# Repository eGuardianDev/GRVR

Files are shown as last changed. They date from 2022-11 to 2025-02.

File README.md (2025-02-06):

<div align="center" display="inline">
  <h1>Gyroscope Tracking (in) Virtual Reality</h1>

<h3>This project allows you to track points in 3d invieroment using gyroscopes.</h3>

<h4>This gives you the ability you to track your body. Uses can be found in VR Gaming, AR interfaces, sport and physical tracking, Location estimation
</h4>
</div>

<br/>
<h2>Current State:</h2>

- [X] Point localization algorithm 
- [X] API implementation
- [X] Custom json file on configuration
- [X] ESP-NOW Communication
- [ ] Controllers
- [ ] Movement algorithm
- [ ] Headset display

<h2> Tech Stack </h2>

||Hardware|Software|Additional|
|:---:|:---:|:---:|:---:|
||ESP8266|AvaloniaUI|SteamVR|
||MPU6050| |Panda3d|
||C++| C#| C++ & Python|

## Documentation

[Documentation](https://github.com/eGuardianDev/GRVR/wiki)

## Limitations
#### 1. Many sensors are needed to track every main point of the body.
#### 2. Every point should have a "parent" point. (Except point zero)

## Pictures
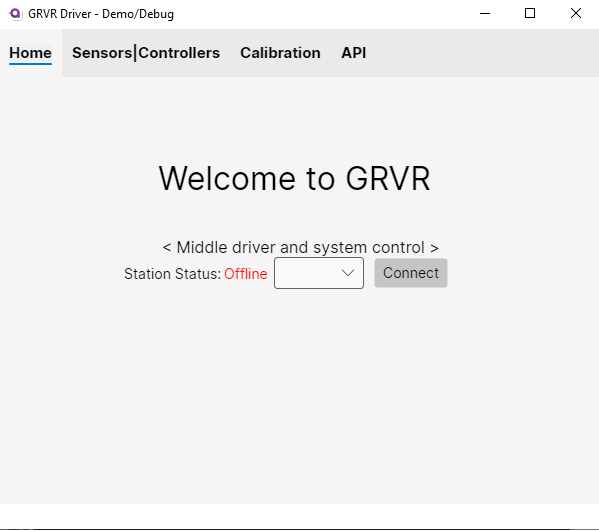
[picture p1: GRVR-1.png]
Main menu

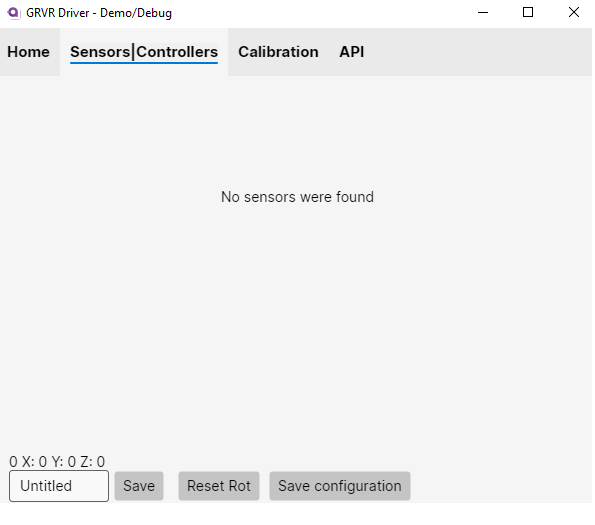
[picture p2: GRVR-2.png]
Sensors

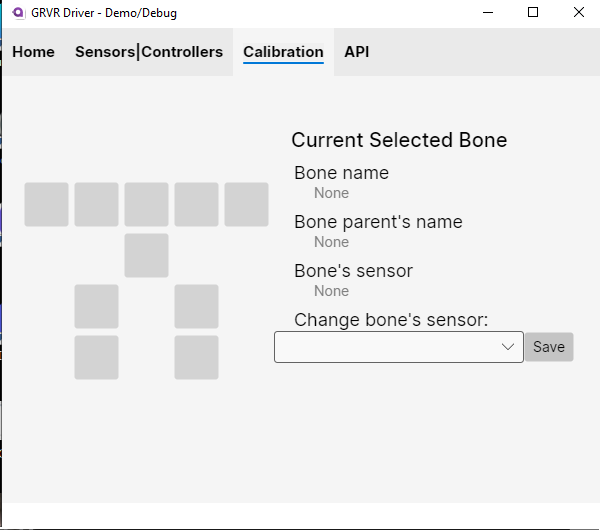
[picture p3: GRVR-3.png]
Set

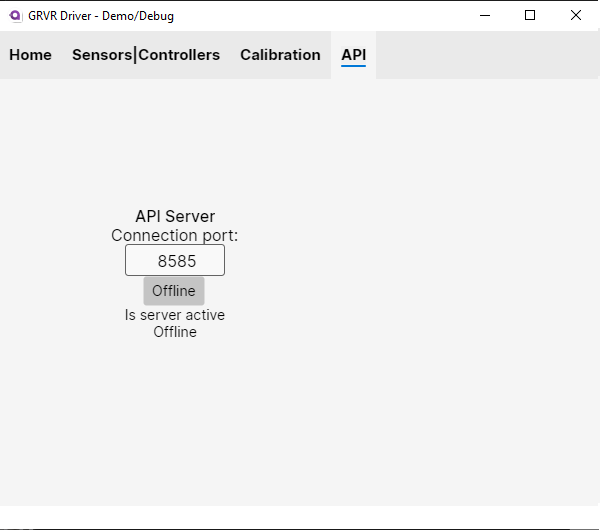
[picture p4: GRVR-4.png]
API

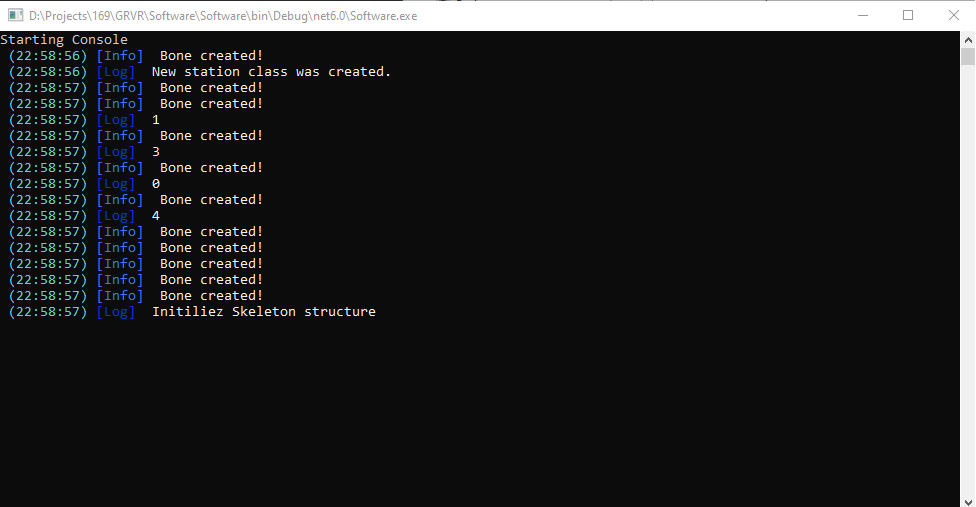
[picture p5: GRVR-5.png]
Console


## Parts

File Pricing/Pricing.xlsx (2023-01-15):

GRVR Pricing
 | BGN | EUR | URL
Sensor |  | 1.36 | https://www.aliexpress.com/item/32340949017.html | Set1 |  | Set2
MPU chip |  |  |  | Sensor | 1.36 | Sensor 2x | 2.72
 |  |  |  | Esp8266 | 2.11 | Esp8267 | 2.11
Esp8266 boards |  | 2.11 |  | Battery | 5.57 | Battery | 5.57
Esp32 boards |  |  | https://www.aliexpress.com/item/32802431728.html | Other | 3 | Other | 3
Controller esp8266 |  |  | https://www.aliexpress.com/item/32339917567.html | PCB | 2 | PCB | 1
Controller esp32
PCB x30 | 30 | 60
 |  |  |  | Eur | 14.04 | Eur | 14.4
 |  |  |  | x16 | 224.64 | x8 | 115.2
 |  |  |  | BGN | 12.04 | BGN | 14.4
 |  |  |  | x16 |  | x8 | 115.2
Battery | 10.9 | 5.57

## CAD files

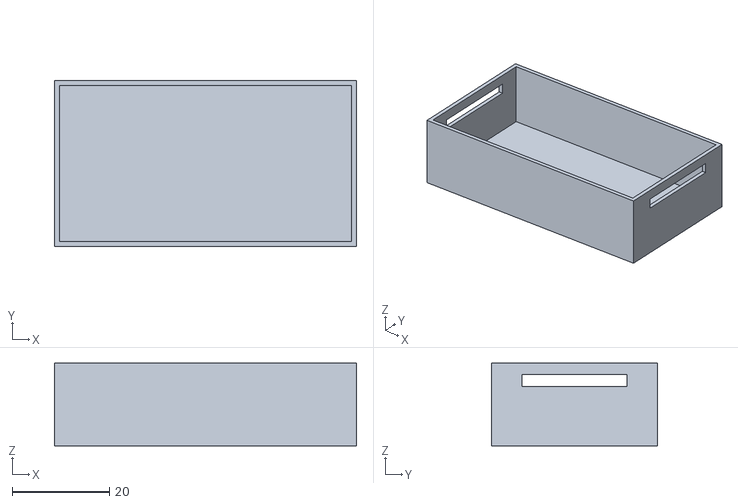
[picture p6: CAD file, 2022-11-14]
3d desing/V0.2/Export STL/V0.2 main-Bottom.stl
62.0 x 34.0 x 17.0

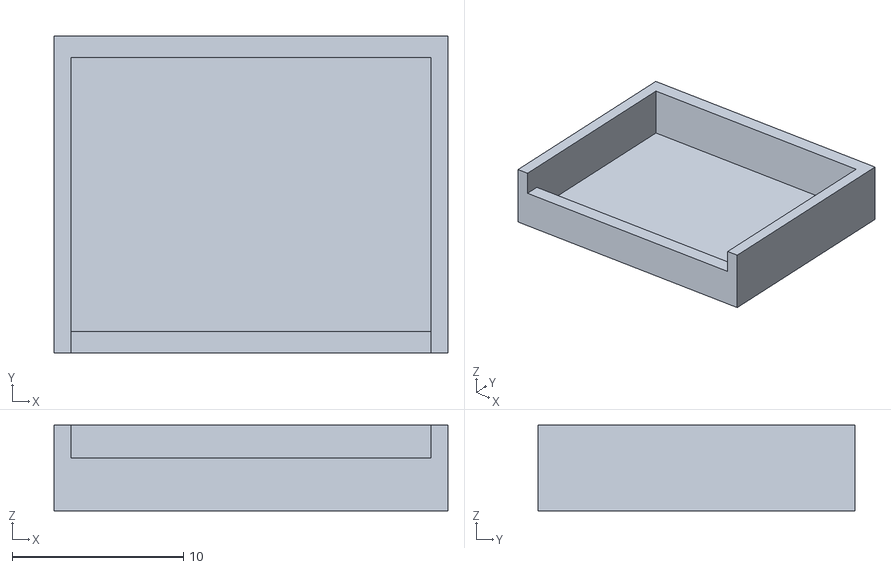
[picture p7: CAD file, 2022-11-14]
3d desing/V0.2/Export STL/V0.2 - Bottom.stl
23.0 x 18.5 x 5.00

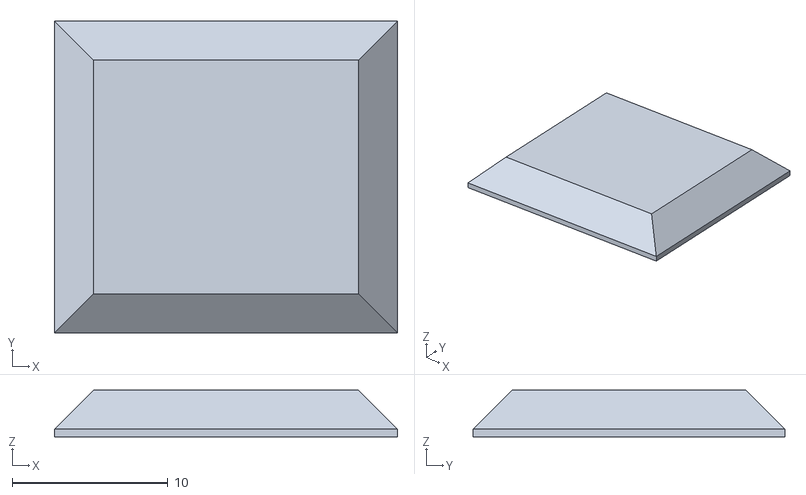
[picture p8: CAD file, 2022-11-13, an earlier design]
3d desing/V0.1/Explort SDL/v0.1 Addon-Top.stl
22.0 x 20.0 x 3.00

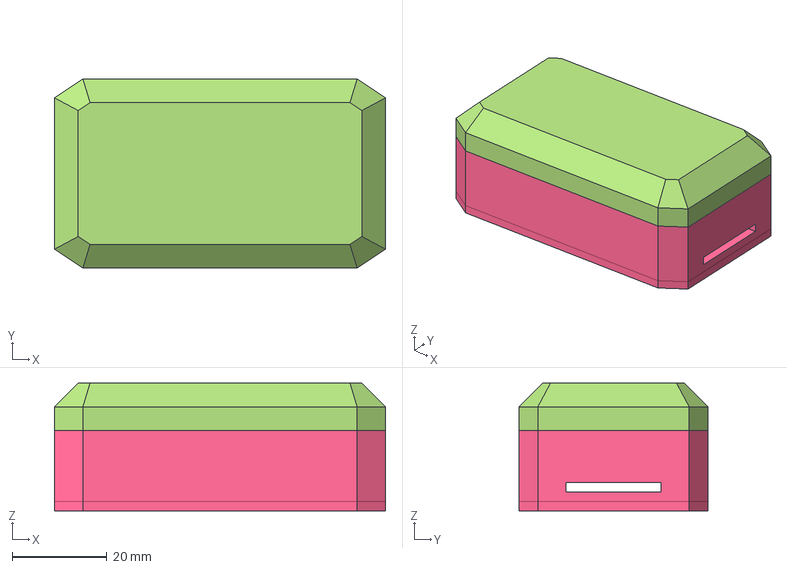
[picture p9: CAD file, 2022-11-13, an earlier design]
3d desing/V0.1/v1.0.FCStd
70.0 x 40.0 x 27.0 mm
Top

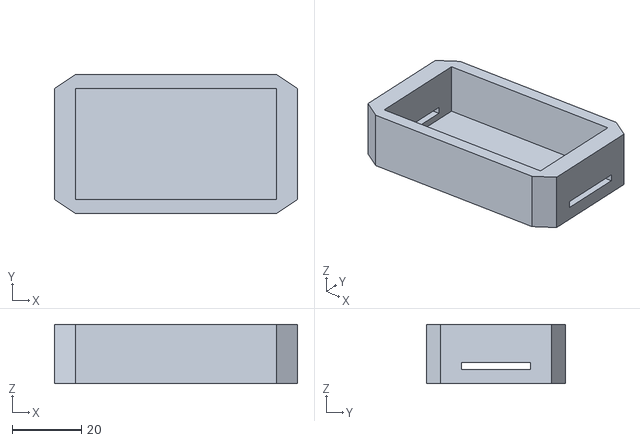
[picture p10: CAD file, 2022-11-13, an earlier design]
3d desing/V0.1/Explort SDL/v0.1-Bottom.stl
70.0 x 40.0 x 17.0

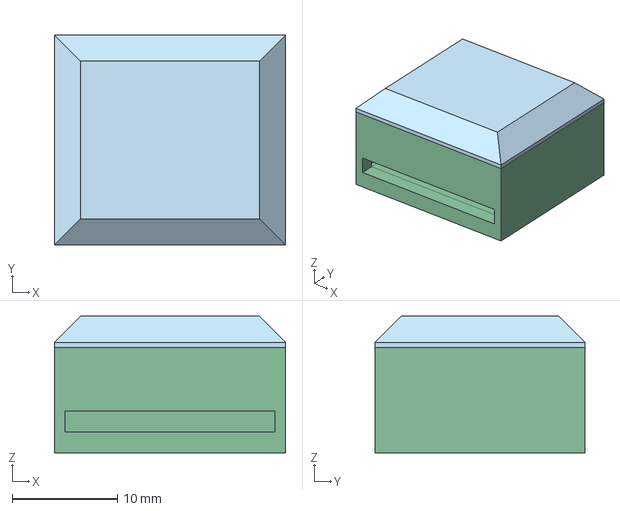
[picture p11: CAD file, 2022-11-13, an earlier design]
3d desing/V0.1/v1.0 Addon.FCStd
22.0 x 20.0 x 13.0 mm
Top

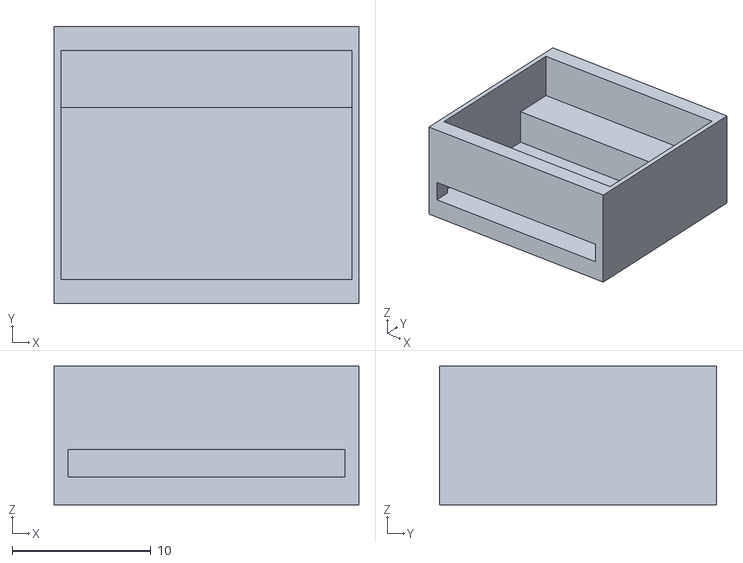
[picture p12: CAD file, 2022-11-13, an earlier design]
3d desing/V0.1/Explort SDL/v0.1 Addon- Botom.stl
22.0 x 20.0 x 10.0

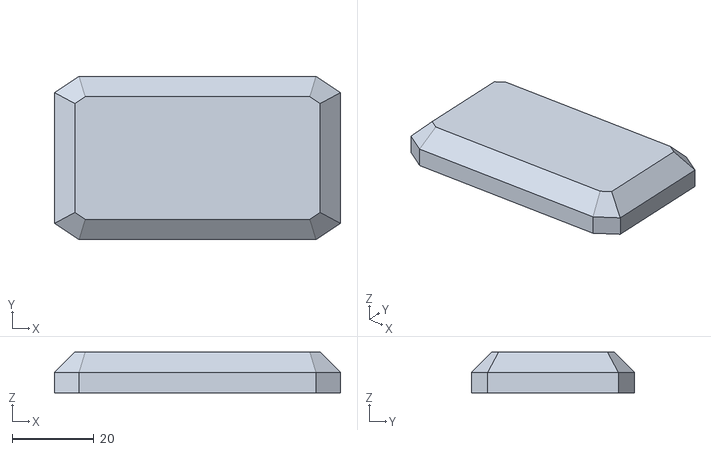
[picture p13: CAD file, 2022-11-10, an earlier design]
3d desing/V0.1/Explort SDL/v0.1-Toppom.stl
70.0 x 40.0 x 10.0

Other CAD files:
3d desing/V0.2/V0.2 main.FCStd
3d desing/V0.2/V0.2 MainModule.FCStd
3d desing/V0.2/V0.2.FCStd
3d desing/V0.1/Explort SDL/v0.1-Bottom NoHoles.stl

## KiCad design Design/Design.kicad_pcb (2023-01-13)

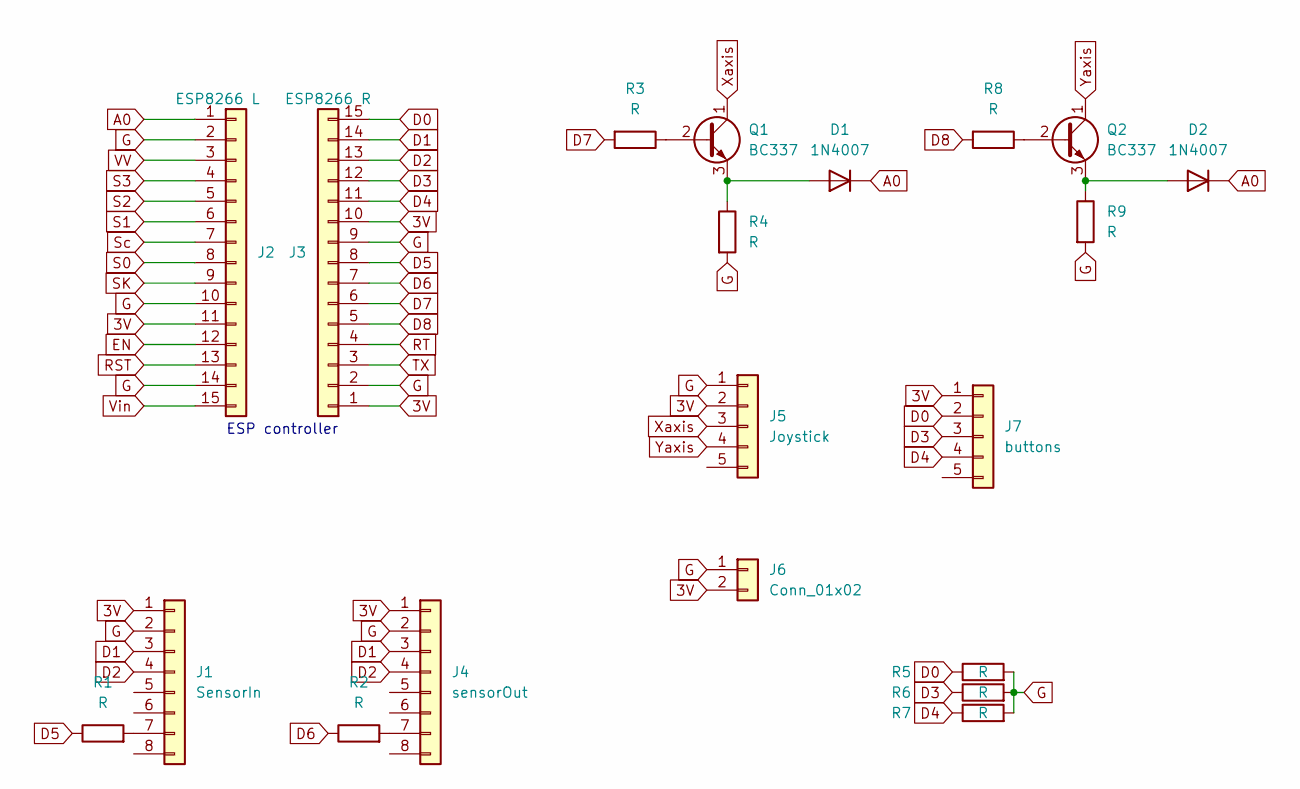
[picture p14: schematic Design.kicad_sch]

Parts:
D1, D2: 1N4007; D_DO-41_SOD81_P10.16mm_Horizontal
J1: SensorIn
J2: ESP8266 L; PinHeader_1x15_P2.54mm_Vertical
J3: ESP8266 R; PinHeader_1x15_P2.54mm_Vertical
J4: sensorOut; PinHeader_1x08_P2.54mm_Vertical
J5: Joystick
J6: Conn_01x02
J7: buttons; PinHeader_1x05_P2.54mm_Vertical
Q1, Q2: BC337; TO-92_Inline
R1: R
R2, R3, R4, R5, R6, R7, R8, R9: R; R_Axial_DIN0204_L3.6mm_D1.6mm_P7.62mm_Horizontal

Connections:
3V: J1.1, J2.11, J3.1, J3.10, J4.1, J5.2, J6.2, J7.1
A0: D1.1 (K), D2.1 (K), J2.1
D0: J3.15, J7.2, R5.1
D1: J1.3, J3.14, J4.3
D2: J1.4, J3.13, J4.4
D3: J3.12, J7.3, R6.1
D4: J3.11, J7.4, R7.1
D5: J3.8, R1.1
D6: J3.7, R2.1
D7: J3.6, R3.2
D8: J3.5, R8.2
EN: J2.12
G: J1.2, J2.2, J2.10, J2.14, J3.2, J3.9, J4.2, J5.1, J6.1, R4.2, R5.2, R6.2, R7.2, R9.2
unnamed: D1.2 (A), Q1.3 (E), R4.1
unnamed: D2.2 (A), Q2.3 (E), R9.1
unnamed: J1.7, R1.2
unnamed: J4.7, R2.2
unnamed: Q1.2 (B), R3.1
unnamed: Q2.2 (B), R8.1
RST: J2.13
RT: J3.4
S0: J2.8
S1: J2.6
S2: J2.5
S3: J2.4
SK: J2.9
Sc: J2.7
TX: J3.3
VV: J2.3
Vin: J2.15
Xaxis: J5.3, Q1.1 (C)
Yaxis: J5.4, Q2.1 (C)

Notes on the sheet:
ESP controller

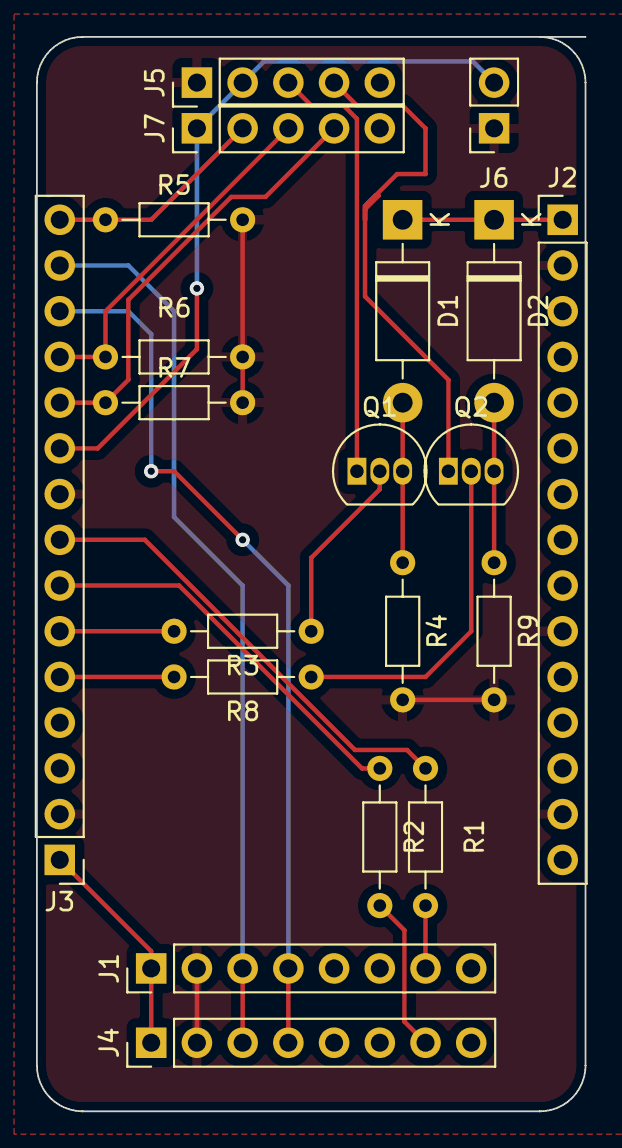
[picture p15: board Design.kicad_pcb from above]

Board: 2 copper layers, 30.5 x 59.7 mm, 20 parts (0 on the bottom side), 20 nets.

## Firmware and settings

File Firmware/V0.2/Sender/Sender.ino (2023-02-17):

//custom library
#include <WString.h>   
#include <Arduino.h>

#include <ESP8266WiFi.h>
#include <espnow.h>

uint8_t broadcastAddress[] = {0xC8, 0xC9, 0xA3, 0x09, 0xCE, 0x16};




#include "Simple_MPU6050.h"

//arduino libraries

//Gyroscope variables
#define MPU6050_ADDRESS_AD0_LOW     0x68
#define MPU6050_ADDRESS_AD0_HIGH    0x69
#define MPU6050_DEFAULT_ADDRESS     MPU6050_ADDRESS_AD0_LOW
#define Three_Axis_Quaternions 3
#define Six_Axis_Quaternions 6  // Default
Simple_MPU6050 mpu(Six_Axis_Quaternions);



String macAdress;
#define NumberOfMPUs 2





#define spamtimer(t) for (static uint32_t SpamTimer; (uint32_t)(millis() - SpamTimer) >= (t); SpamTimer = millis()) 



typedef struct struct_message {
    float x1;
    float y1;
    float z1;
    float x2;
    float y2;
    float z2;
    int code;
} struct_message;

struct_message myData;

unsigned long lastTime = 0;  
unsigned long timerDelay = 100;  // send readings timer

// Callback when data is sent
void OnDataSent(uint8_t *mac_addr, uint8_t sendStatus) {
  Serial.print("Last Packet Send Status: ");
  if (sendStatus == 0){
    Serial.println("Delivery success");
  }
  else{
    Serial.println("Delivery fail");
  }
}

void SendEuler(int32_t *quat, uint16_t SpamDelay = 100) {
    
 


  //caculate angles
  Quaternion q;
  VectorFloat gravity;
  float ypr[3] = { 0, 0, 0 };
  float xyz[3] = { 0, 0, 0 };  int activeMPU;
  spamtimer(SpamDelay) {
    mpu.GetQuaternion(&q, quat);
    mpu.GetGravity(&gravity, &q);
    mpu.GetYawPitchRoll(ypr, &q, &gravity);
    mpu.ConvertToDegrees(ypr, xyz);
   

 // digitalWrite(14, !digitalRead(14));
 // digitalWrite(12, !digitalRead(12)); 
  // if(digitalRead(14) == HIGH){
    activeMPU = 0; 
   
    myData.x1 =  xyz[0];
    myData.y1 =  xyz[1] ;
    myData.z1 =  xyz[2] ;
   }
 // else if(digitalRead(12) == HIGH) {
 //     activeMPU = 1; 
    
    
    myData.x2 =  xyz[0];
    myData.y2 =  xyz[1] ;
    myData.z2 =  xyz[2] ;
    myData.code = 10000;

    esp_now_send(broadcastAddress, (uint8_t *) &myData, sizeof(myData));

   // }
    
  }

    uint32_t Freq = 0;

//some board information
void printBoardInformation(){
  if(!Serial) {return;}
  Serial.print("ESP Board MAC Address:  ");
  Serial.println(macAdress);
  Serial.print("Active MPUs: ");
  Serial.println(NumberOfMPUs);
}

void print_Values (int16_t *gyro, int16_t *accel, int32_t *quat) {
  uint8_t Spam_Delay = 10; 
   SendEuler(quat, Spam_Delay);
}


 
void setup() {
  
  Serial.begin(115200);
  delay(1000);
  printBoardInformation();

//  Freq = getCpuFrequencyMhz();
  //Netowork is ready to be used;



  Serial.println(F("Starting calibrations:"));
  mpu.SetAddress(MPU6050_DEFAULT_ADDRESS);
  mpu.Set_DMP_Output_Rate_Hz(25);           // Set the DMP output rate from 200Hz to 5 Minutes.

 //Setting Pin Modes
  pinMode(14, OUTPUT);
  pinMode(12, OUTPUT);

 // Calibration gyro 1
  //digitalWrite(14, HIGH);
  //digitalWrite(12, LOW);
  mpu.CalibrateMPU().load_DMP_Image();// Does it all for you with Calibration

 // Calibration gyro 2
 // digitalWrite(14, LOW);
 // digitalWrite(12, HIGH);
 // mpu.CalibrateMPU().Enable_Reload_of_DMP(Three_Axis_Quaternions).load_DMP_Image();// Does it all for you with Calibration
  
  //What to do when information is received
  mpu.on_FIFO(print_Values);

  WiFi.mode(WIFI_STA);

  if (esp_now_init() != 0) {
    Serial.println("Error initializing ESP-NOW");
    return;
  }

  esp_now_set_self_role(ESP_NOW_ROLE_CONTROLLER);
  esp_now_register_send_cb(OnDataSent);
  
  esp_now_add_peer(broadcastAddress, ESP_NOW_ROLE_SLAVE, 1, NULL, 0);
}
 
void loop() {
  
  mpu.dmp_read_fifo(0);// Must be in loop
  
  delay(10); 
    
}

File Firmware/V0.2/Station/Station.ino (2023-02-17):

#include <ESP8266WiFi.h>
#include <espnow.h>

typedef struct struct_message {
    float x1;
    float y1;
    float z1;
    float x2;
    float y2;
    float z2;
    int code;
} struct_message;


struct_message myData;

void OnDataRecv(uint8_t * mac, uint8_t *incomingData, uint8_t len) {
  memcpy(&myData, incomingData, sizeof(myData));
 // memcpy(&ReceivedAdd, mac, sizeof(ReceivedAdd));
 // Serial.print("Bytes received: ");
  Serial.print(len);
  Serial.print(myData.code);
 // Serial.println(ReceivedAdd[0]);
  Serial.print(" ");
  Serial.print (myData.x1);
  Serial.print (" ");
  Serial.print (myData.y1);
  Serial.print (" ");
  Serial.print (myData.z1);
  Serial.print (" ");
  Serial.print (myData.x2);
  Serial.print (" ");
  Serial.print (myData.y2);
  Serial.print (" ");
  Serial.println (myData.z2);
}
 
void setup() {
  Serial.begin(115200);
  WiFi.mode(WIFI_STA);

  if (esp_now_init() != 0) {
    Serial.println("Error initializing ESP-NOW");
    return;
  }
  
  esp_now_set_self_role(ESP_NOW_ROLE_SLAVE);
  esp_now_register_recv_cb(OnDataRecv);
}

void loop() {}

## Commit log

2022-11-10 3D design and gitignore for vs 2022
    [body1.stl, body2.stl, v1.0.FCStd]
2022-11-13 idk what i did, i wrote this 2 days ago
    [v1.0.FCStd]
2022-11-13 ore stuff
    [v1.0 Addon- Botom.stl, v1.0 Addon-Top.stl, v1.0 Addon.FCStd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]
2022-11-14 File organization + V0.2 of desing
    [V0.2 - Bottom.stl, V0.2 MainModule.FCStd, V0.2 main-Bottom.stl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]
2022-11-22 It's 12:47 and i wanna sleep. finaly fixed displaying the sensros and connecting the sensors, firmware almost ready
    [Sender.ino, Station.ino, V0.1.ino]
2022-12-15 my sensor died. Sad. This code for the main program isn't complate and there isn't any calibration. I wasn't able to test it, becuase my sensorjust stoped working.
    [Pricing.xlsx]
2023-01-09 pcb design
    [Design-B_Cu.gbr, Design-B_Mask.gbr, Design-B_Paste.gbr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]
